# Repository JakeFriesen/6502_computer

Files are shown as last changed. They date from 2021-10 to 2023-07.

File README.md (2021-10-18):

2020-05-02
Jake Friesen
Using the VASM oldstyle assembler to convert assembly to a binary output for 6502 computers:

1) open CMD and cd to this folder, and have your assembly.txt in this folder
2) run the following command:
	vasm6502_oldstyle.exe -Fbin -dotdir YourFile.txt
-Fbin: outputs a binary file
-dotdir: uses the "." directives (like .org)
The binary file is the a.out file

3) open Xgpro, put the a.out file in, and configure for the right chip (ATMEL AT28C256)
4) load the chip into the programmer, and click "program"

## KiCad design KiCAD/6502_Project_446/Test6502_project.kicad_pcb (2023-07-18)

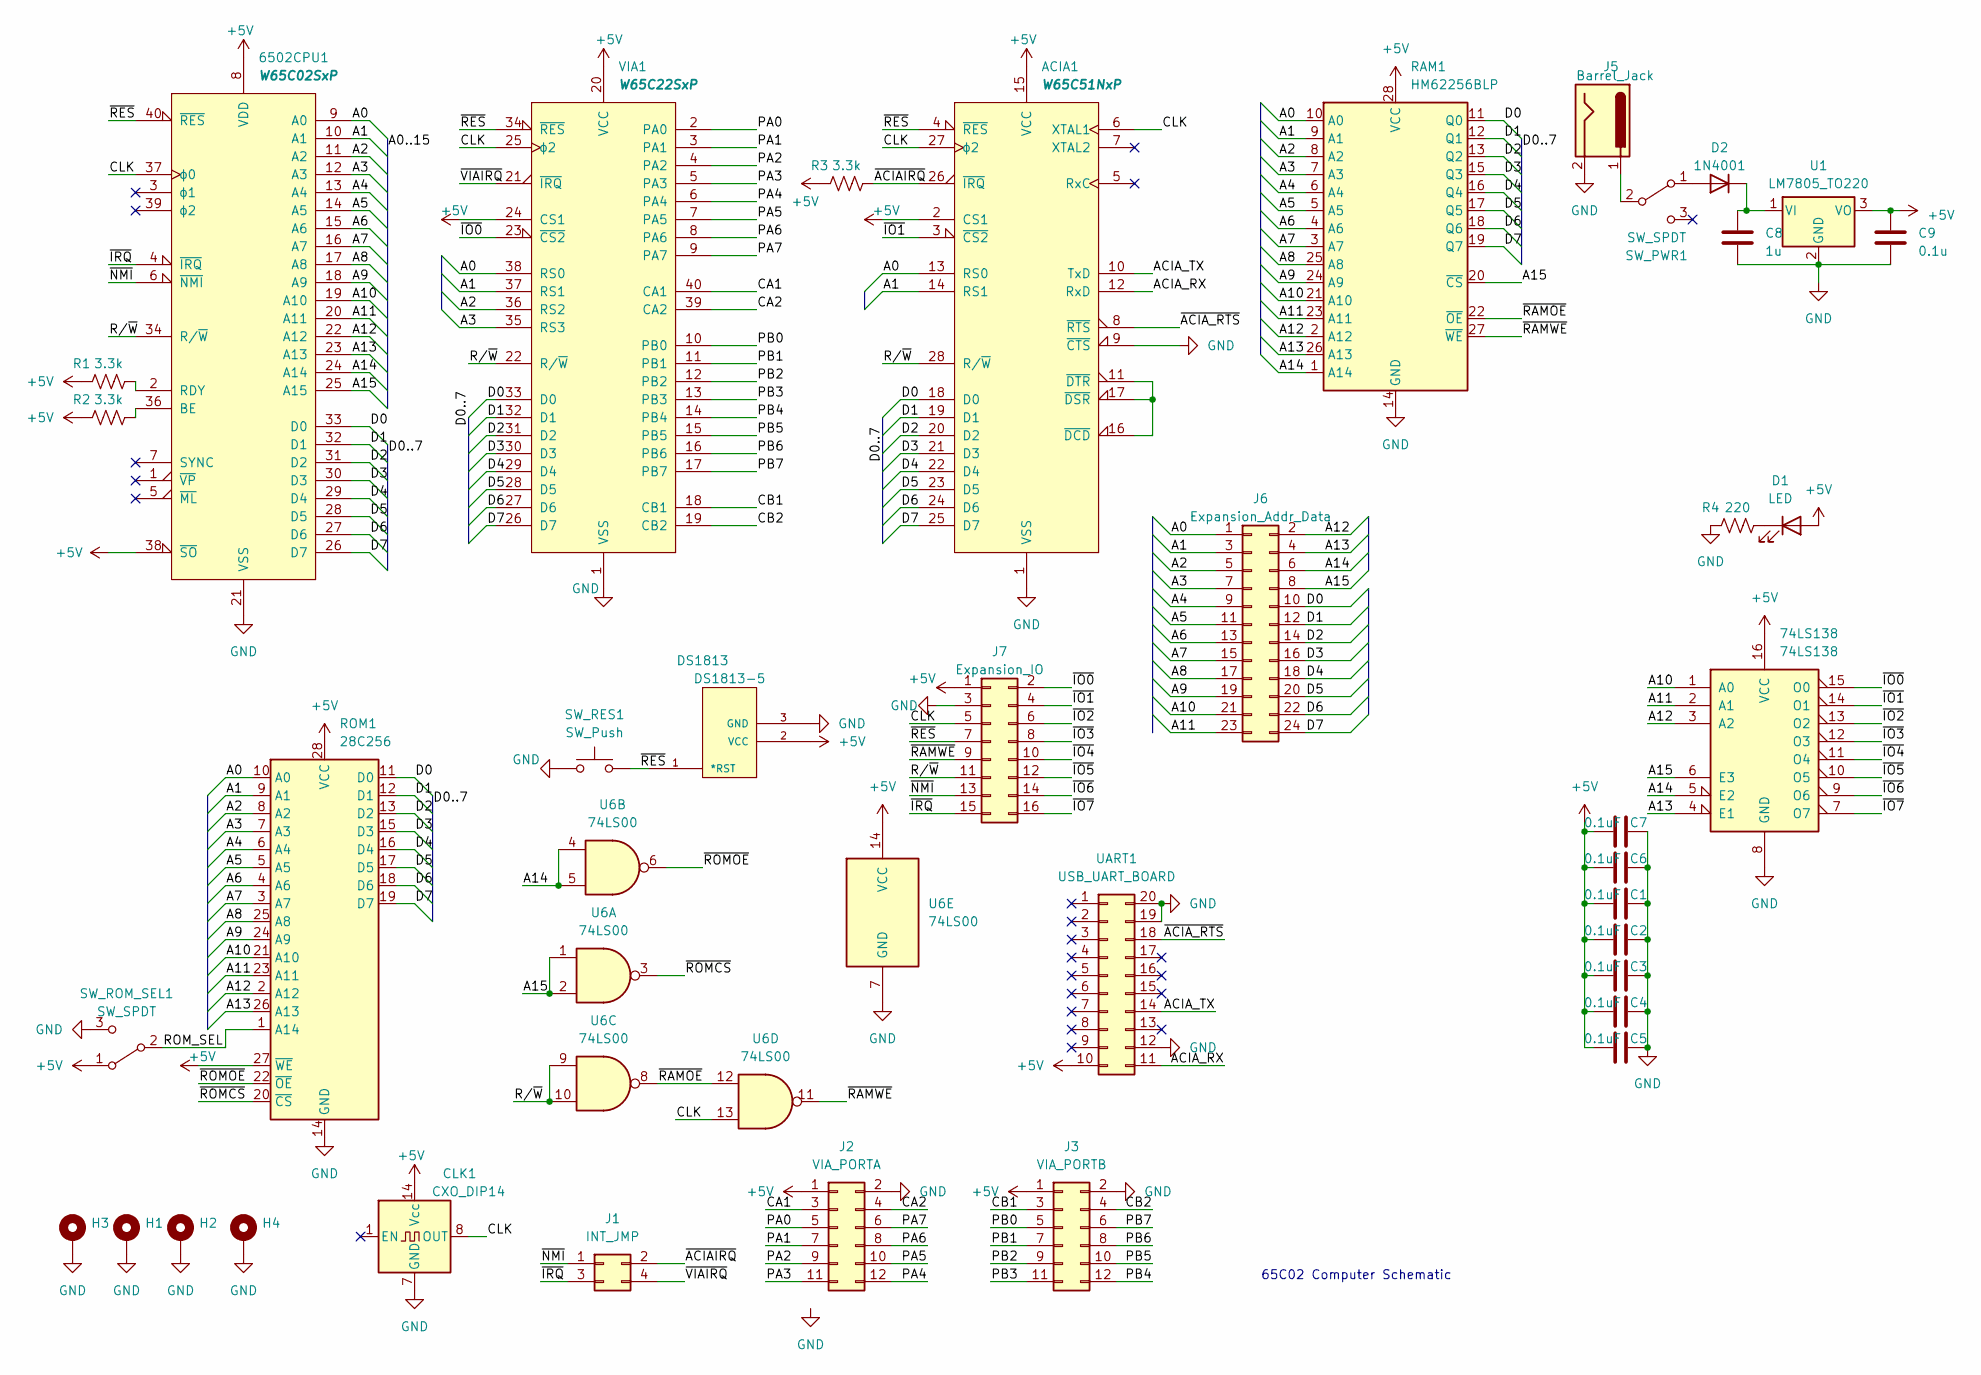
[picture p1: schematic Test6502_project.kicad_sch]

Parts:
74LS138: 74LS138; DIP-16_W7.62mm
6502CPU1: W65C02SxP; DIP-40_W15.24mm_Socket
ACIA1: W65C51NxP; DIP-28_W15.24mm_Socket
C1, C2, C3, C4, C5, C6, C7: 0.1uF; C_Disc_D5.0mm_W2.5mm_P2.50mm
C8: 1u; C_Disc_D5.0mm_W2.5mm_P2.50mm
C9: 0.1u; C_Disc_D5.0mm_W2.5mm_P2.50mm
CLK1: CXO_DIP14; Oscillator_DIP-14
D1: LED; LED_D3.0mm
D2: 1N4001; D_DO-41_SOD81_P10.16mm_Horizontal
DS1813: DS1813-5; 21-0248A; MANUFACTURER_PART_NUMBER ds18135+
H1, H2, H3, H4: MountingHole_Pad; MountingHole_3.2mm_M3_DIN965_Pad
J1: INT_JMP; PinHeader_2x02_P2.54mm_Vertical
J2: VIA_PORTA; PinHeader_2x06_P2.54mm_Vertical
J3: VIA_PORTB; PinHeader_2x06_P2.54mm_Vertical
J5: Barrel_Jack; BarrelJack_Horizontal
J6: Expansion_Addr_Data; PinHeader_2x12_P2.54mm_Vertical
J7: Expansion_IO; PinHeader_2x08_P2.54mm_Vertical
R1, R2, R3: 3.3k; R_Axial_DIN0207_L6.3mm_D2.5mm_P7.62mm_Horizontal
R4: 220; R_Axial_DIN0207_L6.3mm_D2.5mm_P7.62mm_Horizontal
RAM1: HM62256BLP; DIP-28_W15.24mm_Socket
ROM1: 28C256; DIP-28_W15.24mm_Socket
SW_PWR1: SW_SPDT; SW_THT_DPDT
SW_RES1: SW_Push; SW_PUSH_6mm
SW_ROM_SEL1: SW_SPDT; SW_THT_DPDT
U1: LM7805_TO220; TO-220-3_Vertical
U6: 74LS00; DIP-14_W7.62mm
UART1: USB_UART_BOARD; DIP-20_W15.24mm_UART
VIA1: W65C22SxP; DIP-40_W15.24mm_Socket

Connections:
+5V: 74LS138.16 (VCC), 6502CPU1.8 (VDD), 6502CPU1.38 (~SO), ACIA1.2 (CS1), ACIA1.15 (VCC), C1.1, C2.1, C3.1, C4.1, C5.1, C6.1, C7.1, C9.1, CLK1.14 (Vcc), D1.2 (A), DS1813.2 (VCC), J2.1, J3.1, J7.1, R1.1, R2.1, R3.1, RAM1.28 (VCC), ROM1.27 (~WE), ROM1.28 (VCC), SW_ROM_SEL1.1 (A), U1.3 (VO), U6.14 (VCC), UART1.10, VIA1.20 (VCC), VIA1.24 (CS1)
/A0: 6502CPU1.9 (A0), ACIA1.13 (RS0), J6.1, RAM1.10 (A0), ROM1.10 (A0), VIA1.38 (RS0)
/A1: 6502CPU1.10 (A1), ACIA1.14 (RS1), J6.3, RAM1.9 (A1), ROM1.9 (A1), VIA1.37 (RS1)
/A2: 6502CPU1.11 (A2), J6.5, RAM1.8 (A2), ROM1.8 (A2), VIA1.36 (RS2)
/A3: 6502CPU1.12 (A3), J6.7, RAM1.7 (A3), ROM1.7 (A3), VIA1.35 (RS3)
/A4: 6502CPU1.13 (A4), J6.9, RAM1.6 (A4), ROM1.6 (A4)
/A5: 6502CPU1.14 (A5), J6.11, RAM1.5 (A5), ROM1.5 (A5)
/A6: 6502CPU1.15 (A6), J6.13, RAM1.4 (A6), ROM1.4 (A6)
/A7: 6502CPU1.16 (A7), J6.15, RAM1.3 (A7), ROM1.3 (A7)
/A8: 6502CPU1.17 (A8), J6.17, RAM1.25 (A8), ROM1.25 (A8)
/A9: 6502CPU1.18 (A9), J6.19, RAM1.24 (A9), ROM1.24 (A9)
/A10: 74LS138.1 (A0), 6502CPU1.19 (A10), J6.21, RAM1.21 (A10), ROM1.21 (A10)
/A11: 74LS138.2 (A1), 6502CPU1.20 (A11), J6.23, RAM1.23 (A11), ROM1.23 (A11)
/A12: 74LS138.3 (A2), 6502CPU1.22 (A12), J6.2, RAM1.2 (A12), ROM1.2 (A12)
/A13: 74LS138.4 (E1), 6502CPU1.23 (A13), J6.4, RAM1.26 (A13), ROM1.26 (A13)
/A14: 74LS138.5 (E2), 6502CPU1.24 (A14), J6.6, RAM1.1 (A14), U6.4, U6.5
/A15: 74LS138.6 (E3), 6502CPU1.25 (A15), J6.8, RAM1.20 (~CS), U6.1, U6.2
/ACIA_RX: ACIA1.12 (RxD), UART1.11
/ACIA_TX: ACIA1.10 (TxD), UART1.14
/CA1: J2.3, VIA1.40 (CA1)
/CA2: J2.4, VIA1.39 (CA2)
/CB1: J3.3, VIA1.18 (CB1)
/CB2: J3.4, VIA1.19 (CB2)
/CLK: 6502CPU1.37 (ϕ0), ACIA1.6 (XTAL1), ACIA1.27 (ϕ2), CLK1.8 (OUT), J7.5, U6.13, VIA1.25 (ϕ2)
/D0: 6502CPU1.33 (D0), ACIA1.18 (D0), J6.10, RAM1.11 (Q0), ROM1.11 (D0), VIA1.33 (D0)
/D1: 6502CPU1.32 (D1), ACIA1.19 (D1), J6.12, RAM1.12 (Q1), ROM1.12 (D1), VIA1.32 (D1)
/D2: 6502CPU1.31 (D2), ACIA1.20 (D2), J6.14, RAM1.13 (Q2), ROM1.13 (D2), VIA1.31 (D2)
/D3: 6502CPU1.30 (D3), ACIA1.21 (D3), J6.16, RAM1.15 (Q3), ROM1.15 (D3), VIA1.30 (D3)
/D4: 6502CPU1.29 (D4), ACIA1.22 (D4), J6.18, RAM1.16 (Q4), ROM1.16 (D4), VIA1.29 (D4)
/D5: 6502CPU1.28 (D5), ACIA1.23 (D5), J6.20, RAM1.17 (Q5), ROM1.17 (D5), VIA1.28 (D5)
/D6: 6502CPU1.27 (D6), ACIA1.24 (D6), J6.22, RAM1.18 (Q6), ROM1.18 (D6), VIA1.27 (D6)
/D7: 6502CPU1.26 (D7), ACIA1.25 (D7), J6.24, RAM1.19 (Q7), ROM1.19 (D7), VIA1.26 (D7)
/PA0: J2.5, VIA1.2 (PA0)
/PA1: J2.7, VIA1.3 (PA1)
/PA2: J2.9, VIA1.4 (PA2)
/PA3: J2.11, VIA1.5 (PA3)
/PA4: J2.12, VIA1.6 (PA4)
/PA5: J2.10, VIA1.7 (PA5)
/PA6: J2.8, VIA1.8 (PA6)
/PA7: J2.6, VIA1.9 (PA7)
/PB0: J3.5, VIA1.10 (PB0)
/PB1: J3.7, VIA1.11 (PB1)
/PB2: J3.9, VIA1.12 (PB2)
/PB3: J3.11, VIA1.13 (PB3)
/PB4: J3.12, VIA1.14 (PB4)
/PB5: J3.10, VIA1.15 (PB5)
/PB6: J3.8, VIA1.16 (PB6)
/PB7: J3.6, VIA1.17 (PB7)
/ROM_SEL: ROM1.1 (A14), SW_ROM_SEL1.2 (B)
/R/~W: 6502CPU1.34 (R/~W), ACIA1.28 (R/~W), J7.11, U6.9, U6.10, VIA1.22 (R/~W)
/~ACIAIRQ: ACIA1.26 (~IRQ), J1.2, R3.2
/~ACIA_RTS: ACIA1.8 (~RTS), UART1.18
/~IO0: 74LS138.15 (O0), J7.2, VIA1.23 (~CS2)
/~IO1: 74LS138.14 (O1), ACIA1.3 (~CS2), J7.4
/~IO2: 74LS138.13 (O2), J7.6
/~IO3: 74LS138.12 (O3), J7.8
/~IO4: 74LS138.11 (O4), J7.10
/~IO5: 74LS138.10 (O5), J7.12
/~IO6: 74LS138.9 (O6), J7.14
/~IO7: 74LS138.7 (O7), J7.16
/~IRQ: 6502CPU1.4 (~IRQ), J1.3, J7.15
/~NMI: 6502CPU1.6 (~NMI), J1.1, J7.13
/~RAMOE: RAM1.22 (~OE), U6.8, U6.12
/~RAMWE: J7.9, RAM1.27 (~WE), U6.11
/~RES: 6502CPU1.40 (~RES), ACIA1.4 (~RES), DS1813.1 (*RST), J7.7, SW_RES1.2, VIA1.34 (~RES)
/~ROMCS: ROM1.20 (~CS), U6.3
/~ROMOE: ROM1.22 (~OE), U6.6
/~VIAIRQ: J1.4, VIA1.21 (~IRQ)
GND: 74LS138.8 (GND), 6502CPU1.21 (VSS), ACIA1.1 (VSS), ACIA1.9 (~CTS), C1.2, C2.2, C3.2, C4.2, C5.2, C6.2, C7.2, C8.2, C9.2, CLK1.7 (GND), DS1813.3 (GND), H1.1, H2.1, H3.1, H4.1, J2.2, J3.2, J5.2, J7.3, R4.1, RAM1.14 (GND), ROM1.14 (GND), SW_RES1.1, SW_ROM_SEL1.3 (C), U1.2 (GND), U6.7 (GND), UART1.12, UART1.19, UART1.20, VIA1.1 (VSS)
unnamed: 6502CPU1.36 (BE), R2.2
unnamed: 6502CPU1.2 (RDY), R1.2
unnamed: ACIA1.11 (~DTR), ACIA1.16 (~DCD), ACIA1.17 (~DSR)
unnamed: D1.1 (K), R4.2
unnamed: D2.2 (A), SW_PWR1.1 (A)
unnamed: C8.1, D2.1 (K), U1.1 (VI)
unnamed: J5.1, SW_PWR1.2 (B)

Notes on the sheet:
65C02 Computer Schematic

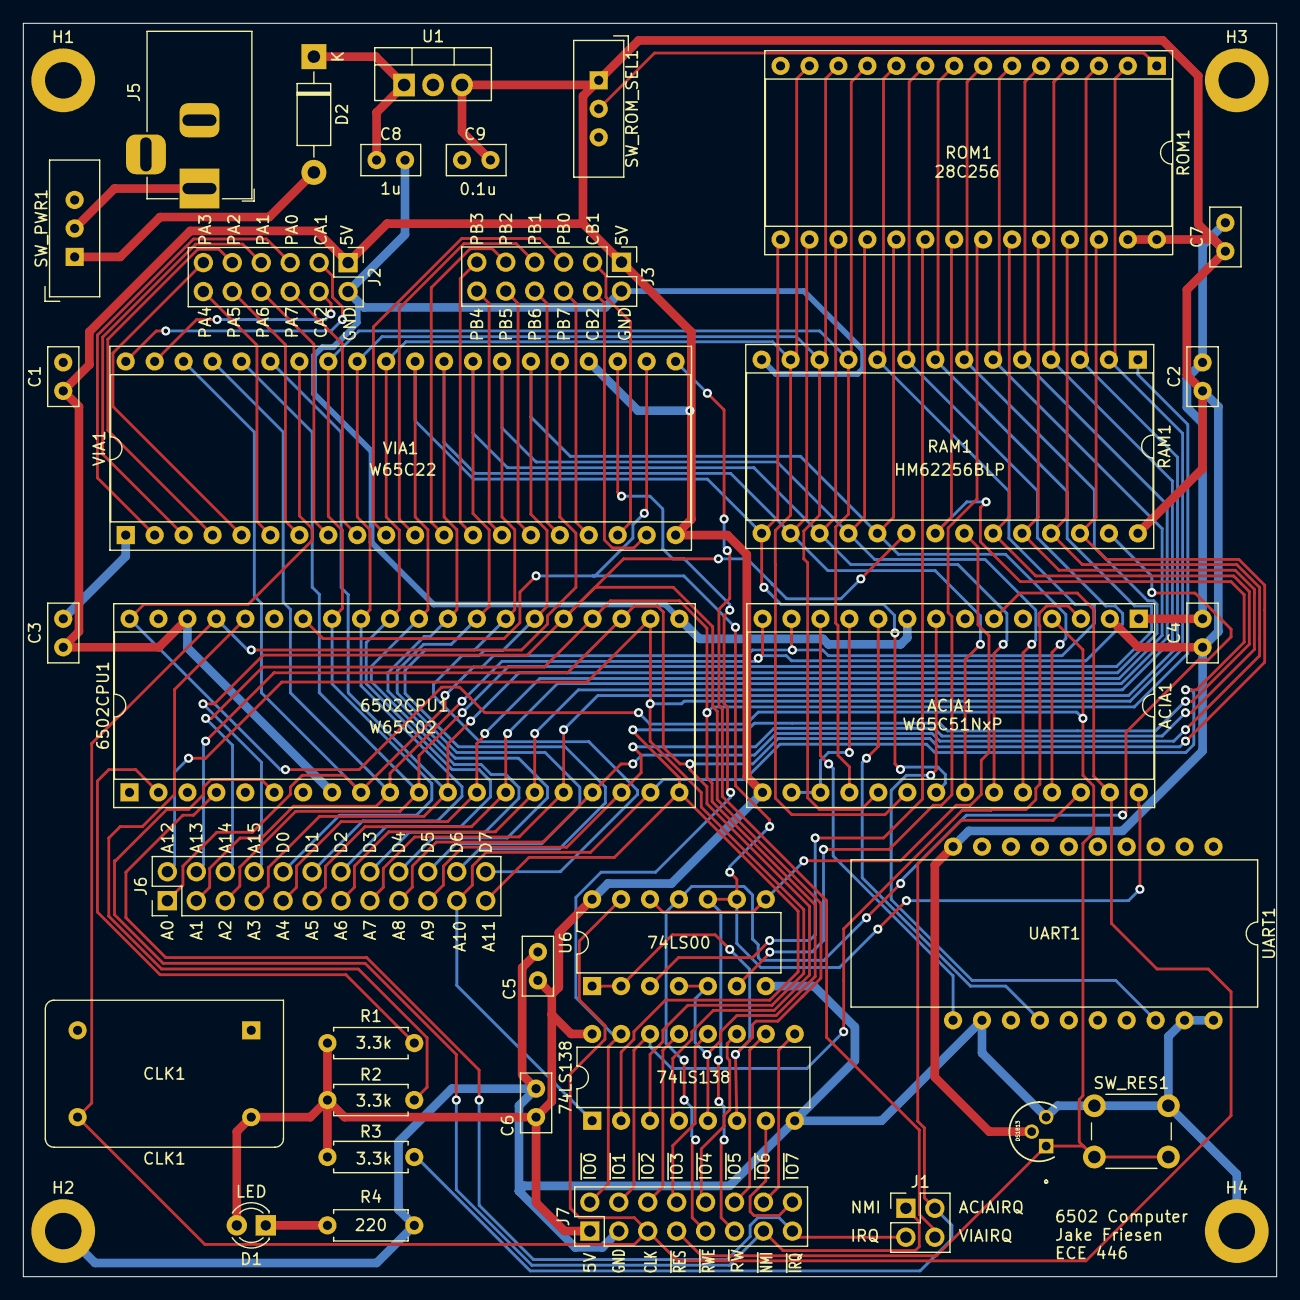
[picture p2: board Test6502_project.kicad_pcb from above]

Board: 2 copper layers, 110.0 x 110.0 mm, 39 parts (0 on the bottom side), 76 nets.

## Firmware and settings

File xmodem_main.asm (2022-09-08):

.setcpu "6502"
.psc02
;Add Libraries
.include "keyboard_lib.asm"
.include "acia_lib.asm"
.include "lcd_lib.asm"
.include "xmodem_lib.asm"

.import XModemRcv


; VIA mem locations
PORTB = $6000
PORTA = $6001
DDRB = $6002
DDRA = $6003
PCR = $600c
IFR = $600d
IER = $600e

; Serial mem locations
ACIA_RX = $4000
ACIA_TX = $4000
ACIA_STATUS = $4001
ACIA_COMMAND = $4002
ACIA_CONTROL = $4003

; Keyboard pointers
kb_wptr = $0000
kb_rptr = $0001
kb_flags = $0002

; Special keys
RELEASE = %00000001
SHIFT   = %00000010

; 256-byte kb buffer 0200-02ff
kb_buffer = $0200  

E  = %01000000
RW = %00100000
RS = %00010000


  .org $8000

reset:
  ldx #$ff
  txs

  ; ACIA setup
  lda #$00
  sta ACIA_STATUS
  lda #$0b
  sta ACIA_COMMAND
  lda #$1f
  sta ACIA_CONTROL

  ; VIA Setup
  lda #$01
  sta PCR
  lda #$82
  sta IER
  cli

  lda #%11111111 ; Set all pins on port B to output
  sta DDRB
  lda #%00000000 ; Set all pins on port A to input
  sta DDRA

  jsr lcd_init
  lda #%00101000 ; Set 4-bit mode; 2-line display; 5x8 font
  jsr lcd_instruction
  lda #%00001110 ; Display on; cursor on; blink off
  jsr lcd_instruction
  lda #%00000110 ; Increment and shift cursor; don't shift display
  jsr lcd_instruction
  lda #%00000001 ; Clear display
  jsr lcd_instruction

  lda #$00
  sta kb_flags
  sta kb_wptr
  sta kb_rptr

;Print out Serial stuff
  ldx #0
nextchar:
  lda message, x
  beq loop
  jsr print_char
  ; just in case it was clobbered?
  lda message, x
  jsr print_char_acia
  inx
  jmp nextchar

message: .asciiz "START"

; Go into XModem Recieve 
  JSR XModemRcv

loop: ; program ended, halt
    jmp loop


nmi:
  rti
; Reset/IRQ vectors
  .org $fffa
  .word nmi
  .word reset
  .word keyboard_interrupt

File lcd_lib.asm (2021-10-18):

;-----------------------------------------------;
;                 LCD Library                   ;
;-----------------------------------------------;

lcd_wait:
  pha
  lda #%11110000  ; LCD data is input
  sta DDRB
lcdbusy:
  lda #RW
  sta PORTB
  lda #(RW | E)
  sta PORTB
  lda PORTB       ; Read high nibble
  pha             ; and put on stack since it has the busy flag
  lda #RW
  sta PORTB
  lda #(RW | E)
  sta PORTB
  lda PORTB       ; Read low nibble
  pla             ; Get high nibble off stack
  and #%00001000
  bne lcdbusy

  lda #RW
  sta PORTB
  lda #%11111111  ; LCD data is output
  sta DDRB
  pla
  rts

lcd_init:
  lda #%00000010 ; Set 4-bit mode
  sta PORTB
  ora #E
  sta PORTB
  and #%00001111
  sta PORTB
  rts

lcd_instruction:
  jsr lcd_wait
  pha
  lsr
  lsr
  lsr
  lsr            ; Send high 4 bits
  sta PORTB
  ora #E         ; Set E bit to send instruction
  sta PORTB
  eor #E         ; Clear E bit
  sta PORTB
  pla
  and #%00001111 ; Send low 4 bits
  sta PORTB
  ora #E         ; Set E bit to send instruction
  sta PORTB
  eor #E         ; Clear E bit
  sta PORTB
  rts

print_char:
  jsr lcd_wait
  pha
  lsr
  lsr
  lsr
  lsr             ; Send high 4 bits
  ora #RS         ; Set RS
  sta PORTB
  ora #E          ; Set E bit to send instruction
  sta PORTB
  eor #E          ; Clear E bit
  sta PORTB
  pla
  and #%00001111  ; Send low 4 bits
  ora #RS         ; Set RS
  sta PORTB
  ora #E          ; Set E bit to send instruction
  sta PORTB
  eor #E          ; Clear E bit
  sta PORTB
  rts

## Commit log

2022-09-08 Conversion to cc65 successful! Still very rough
    [mem_map.cfg]
2022-09-09 Makefile to run assembler and linker
2023-07-18 Added KiCAD project
    [65xx.SchLib, DS1813-5.PcbLib, DS1813-5.SchLib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]
